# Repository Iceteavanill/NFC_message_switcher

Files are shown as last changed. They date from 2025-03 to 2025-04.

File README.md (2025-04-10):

[comment]: <> "LTeX: language=en-GB"

# NFC message switcher

This project is an implementation of an NFC tag which is able to change the message. It communicates to a host device. It was developed to be quickly assembled and easy to use but still be a bit more than a blinking light. It uses the reference implementation for the [bare metal TWI driver](https://github.com/microchip-pic-avr-examples/attiny1627-bare-metal-twi-mplab).
PCB render

## Main principle of operation

The main device is the [ST25DV04K](https://www.st.com/resource/en/datasheet/st25dv04k.pdf). 
It can communicate via NFC and I2C. 
When an NFC capable device is held near the PCB, the ST25DV04K starts to receive power and starts communicating with the device. 
The Power that's transmitted is shared (energy harvesting mode) with a [ATtiny402](http://ww1.microchip.com/downloads/en/DeviceDoc/ATtiny202-402-AVR-MCU-with-Core-Independent-Peripherals_and-picoPower-40001969A.pdf). 
When powered it starts communicating via I2C and writes to the user accessible memory. 
When the written data has been confirmed, it powers down.

## Details

### Power

Power provider is the energy harvesting mode of the ST25DV04K, the power source is a NFC capable device that is in proximity of the PCB.
It is buffered via a 47μF capacitor.
Because of that, it is essential to keep the power consumption of the ATtiny as low as possible.
Consult the source code for more details.

### Link arbitration

The ST25DV04K does only support I2C *or* NFC active at the same time. 
However, it has an open drain output that can be used to sense the current activity. 
Low, signals that the device is currently busy. 
The ATtiny then waits for the device to be available, by waiting in sleep. 
A hardware interrupt is not yet implemented.

### Device configuration

The ST25DV04K needs some configuration for correct operation. 
The energy harvesting mode must be enabled/forced at startup. 
Also, the GPO mode must be set to RF_ACTIVITY_EN to enable better link arbitration.
The configuration happens after the ATtiny has been programmed once.

### Antenna

The antenna / coil design is based on a [paper](https://www.researchgate.net/publication/339137261_Inductance_Formula_for_Rectangular_Planar_Spiral_Inductors_with_Rectangular_Conductor_Cross_Section) from Hubert Aebischer. 
The ST25DV04K has an internal tuning capacitor which should be assumed to be 29pF.
Based on that, the inductance should be 4.75μH. 

### Formfactor

The PCB dimensions are the same as a credit card.
It is however quite a bit thicker.

# Building your own

All required files to recreate this project can be found [here](https://github.com/Iceteavanill/NFC_message_switcher/releases/tag/1.0.0). 

## Sourcing

The following parts are needed to recreate this Project (as well as the PCB):

| Reference 	| Value 	| Qty 	| Digikey number 	|
|:---:	|:---:	|:---:	|:---:	|
| C1, C3 	| 0.1uF 	|  2  	| 1276-1000-1-ND 	|
| C2 	| 47uF 	|  1  	| 1276-3063-2-ND 	|
| R1, R2 	| 4k7 	|  2  	| MMA-4.7KACT-ND 	|
| U1 	| ATtiny402 	|  1  	| ATTINY402-SSNRCT-ND 	|
| U2 	| ST25DV04K 	|  1  	| 497-17123-1-ND 	|

## Assembly

There are no special requirements for the assembly of the PCB's. 
If you are used to soldering SMD components it shouldn0t be a problem. 

## Software

You can use the provided released hex file, however it is recommended to customize the software to your own taste. 

There are multiple options to customize the software

> [!WARNING]  
> I tried making the process of using the software as easy as possible, however it may not be very easy/beginner-friendly in places.

### Overview

Customizing the software always requires a rebuild of the firmware of the Attiny. 
The XC8 compiler from microchip is recommended. 
The following flags were used and are recommended:

| Flags | commands |
|---|---|
| Global | -gdwarf-3 -mconst-data-in-progmem -mno-const-data-in-config-mapped-progmem |
| compiler | -funsigned-char -funsigned-bitfields -Wall -O2 -fno-common |
| linker | "libm" -Wl,--gc-sections |

A makefile is already prepared with all the required flags. 
If you install a later version you might have to alter the paths a little.

For customization, only a header file has to be altered (```nfc_messages.h```).  
There are multiple ways of accomplishing that:

 * editing the header directly (not recommended)
 * using the python script
 * using the gui (recommended)

### Editing the header directly

Editing the header directly is not recommended because the required data must be in the NDEF format. 
Manually generating that is very tedious. 
If you have special needs however, like encoding special data types, you have to do it this way because anything else has not been implemented.

### Using the pyton script

The ```dataGenerator.py``` python script can be used to quickly generate custom messages. 
It requires the NDEFLib python library. 
Edit the ```message_as_text_list``` list with your messages and then run the script:
```py
message_as_text_list = ["Test 1",
                        "Test 2 a bit longer",
                        "Test 3 even looooooooooooooooooooooooooonger",
                        "https://www.youtube.com/watch?v=dQw4w9WgXcQ",
                        "spotify:track:4cOdK2wGLETKBW3PvgPWqT"
]
```
### Using the gui

A gui has been made to quickly program multiple NFC tags. 
It requires WXpython and uses the previously mentioned script and the ```message_as_text_list```.
For uploading, it relies on the MPLAB IPE programming software and its command line interface.

Programming steps:

1. Step:

Enter your desired message(s) in the table at the top. 
Links to websites videos or Spotify songs are also allowed.

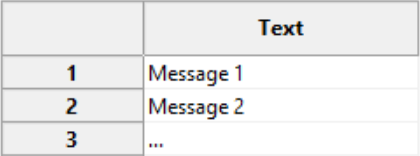
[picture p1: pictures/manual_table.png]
picture of the table


2. Step:

If your main device is an iPhone check the ```iPhone compatability mode```. 
IPhones are unable to read text from a NFC device, and the text messages have to be encoded as a website.

3. Step:

Some default messages are added to the list automatically. If you don't want that, you can disable that with the checkbox ```Remove predefined texts```. 
The ```message_as_text_list``` from ```dataGenerator.py``` is used as a source.

4. Step:

Connect your programmer to the tag and press program device. 
The build and upload steps are automatically executed.

### Building and uploading

In all options but the gui you have to manually build and then upload the firmware. 
You can use the ``` make upload ``` command with the option ``` PROGTOOL= ``` to select the programmer that you have on hand. 
See the documentation of the IPE programmer option to know which flag you have to use.

## Batch programming

Many devices in a row can be programmed with the programming jig:

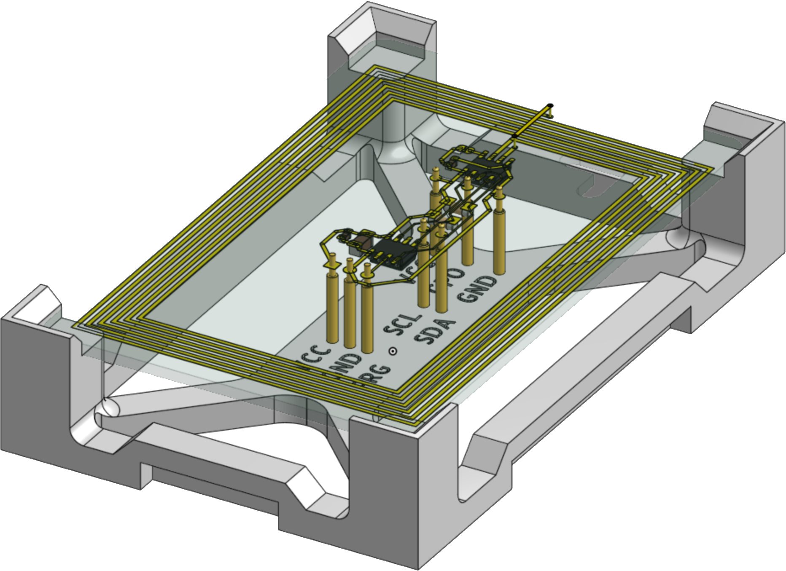
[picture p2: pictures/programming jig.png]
programming jig


It was designed in Onshape. 
I used pogopins that I had on hand. 
You probably want to customize it to your current stock. 
You find the Onshape document [here](https://cad.onshape.com/documents/450623688917edcaa975b9e7/w/39588c936aa9381f65fac7c0/e/be57d568f84f27791dc539d2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).

## Rating GUI

Because this PCB was designed as a competition PCB, a rating gui has been made using streamlit. 
You can import a CSV of contestants and rate each one for time, quality and some other points. 
It is meant to be customized to your particular use case. 

# Caveat

It must be noted that the current design has a (obvious) flaw. 
The ATtiny is in the middle of the coil and *probably* quite affected by the activity of it. 
When combined with the nonideal power delivery method, this can significantly impair functionality at times (The I2C content that is written gets verified but I2C has no error correcting method).
Some more analysis in that regard is not yet made.

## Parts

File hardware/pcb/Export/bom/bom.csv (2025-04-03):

Reference | Value | Datasheet | Footprint | Qty | DNP | Digikeynumber
C1 | 0.1uF | ~ | Capacitor_SMD:C_0603_1608Metric_Pad1.08x0.95mm_HandSolder | 1 |  | 1276-1000-1-ND
C2 | 47uF | ~ | Capacitor_SMD:C_1206_3216Metric_Pad1.33x1.80mm_HandSolder | 1 |  | 1276-3063-2-ND
C3 | 0.1uF | ~ | Capacitor_SMD:C_0603_1608Metric_Pad1.08x0.95mm_HandSolder | 1 | DNP | 1276-1000-1-ND
R1,R2 | 4k7 | ~ | Resistor_SMD:R_MiniMELF_MMA-0204 | 2 |  | MMA-4.7KACT-ND
U1 | ATtiny402 | http://ww1.microchip.com/downloads/en/DeviceDoc/ATtiny202-402-AVR-MCU-with-Core-Independent-Peripherals_and-picoPower-40001969A.pdf | Package_SO:SOIC-8_3.9x4.9mm_P1.27mm | 1 |  | ATTINY402-SSNRCT-ND
U2 | ST25DV04K | https://www.st.com/resource/en/datasheet/st25dv04k.pdf | Package_SO:SOIC-8-1EP_3.9x4.9mm_P1.27mm_EP2.29x3mm | 1 |  | 497-17123-1-ND

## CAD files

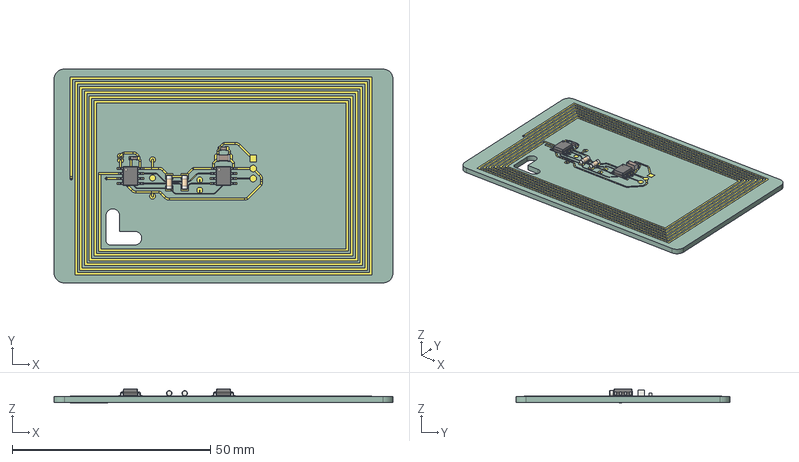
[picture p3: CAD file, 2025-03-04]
hardware/pcb/Export/step/nfc tag.step
85.6 x 54.0 x 3.44 mm
SOIC_8_39x49mm_P127mm x 2
C_0603_1608Metric x 2
R_MiniMELF_MMA-0204 x 2
C_1206_3216Metric
nfc_tag_track_1
nfc_tag_track_2
nfc_tag_track_3
nfc_tag_track_4
nfc_tag_track_5
nfc_tag_track_6
nfc_tag_track_7
nfc_tag_track_8
nfc_tag_track_9
nfc_tag_track_10
nfc_tag_track_11
nfc_tag_track_12
nfc_tag_track_13
nfc_tag_track_14
nfc_tag_track_15
nfc_tag_track_16
nfc_tag_track_17
nfc_tag_track_18
nfc_tag_track_19
nfc_tag_track_20
nfc_tag_track_21
nfc_tag_track_22
nfc_tag_track_23
nfc_tag_track_24
nfc_tag_track_25
nfc_tag_track_26
nfc_tag_track_27
nfc_tag_track_28
nfc_tag_track_29
nfc_tag_track_30
nfc_tag_track_31
nfc_tag_track_32
nfc_tag_track_33
nfc_tag_track_34
nfc_tag_track_35
nfc_tag_track_36
nfc_tag_track_37
nfc_tag_track_38
nfc_tag_track_39
nfc_tag_track_40
nfc_tag_track_41
nfc_tag_track_42
nfc_tag_track_43
nfc_tag_track_44
nfc_tag_track_45
nfc_tag_track_46
nfc_tag_track_47
nfc_tag_track_48
nfc_tag_track_49
nfc_tag_track_50
nfc_tag_track_51
nfc_tag_track_52
nfc_tag_track_53
nfc_tag_track_54
nfc_tag_track_55
nfc_tag_track_56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

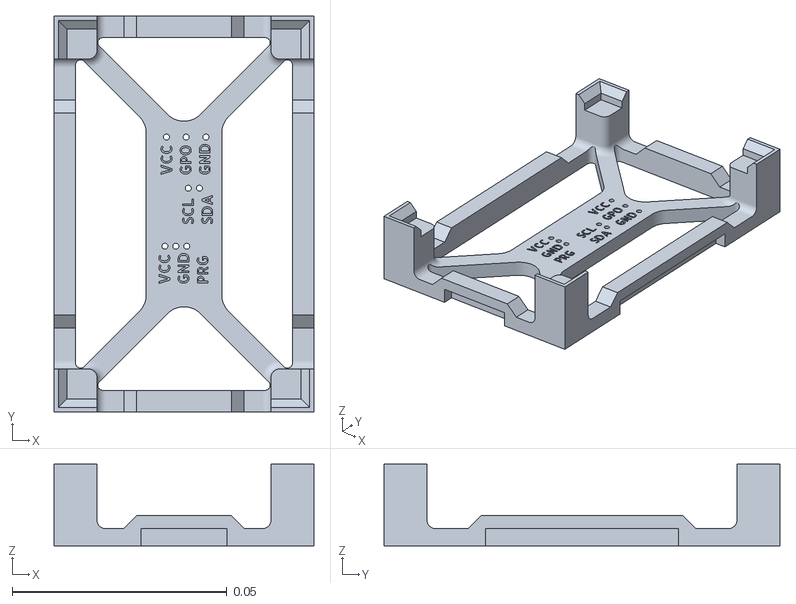
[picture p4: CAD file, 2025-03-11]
hardware/programming jig/programming jig.stl
0.0605 x 0.0921 x 0.019

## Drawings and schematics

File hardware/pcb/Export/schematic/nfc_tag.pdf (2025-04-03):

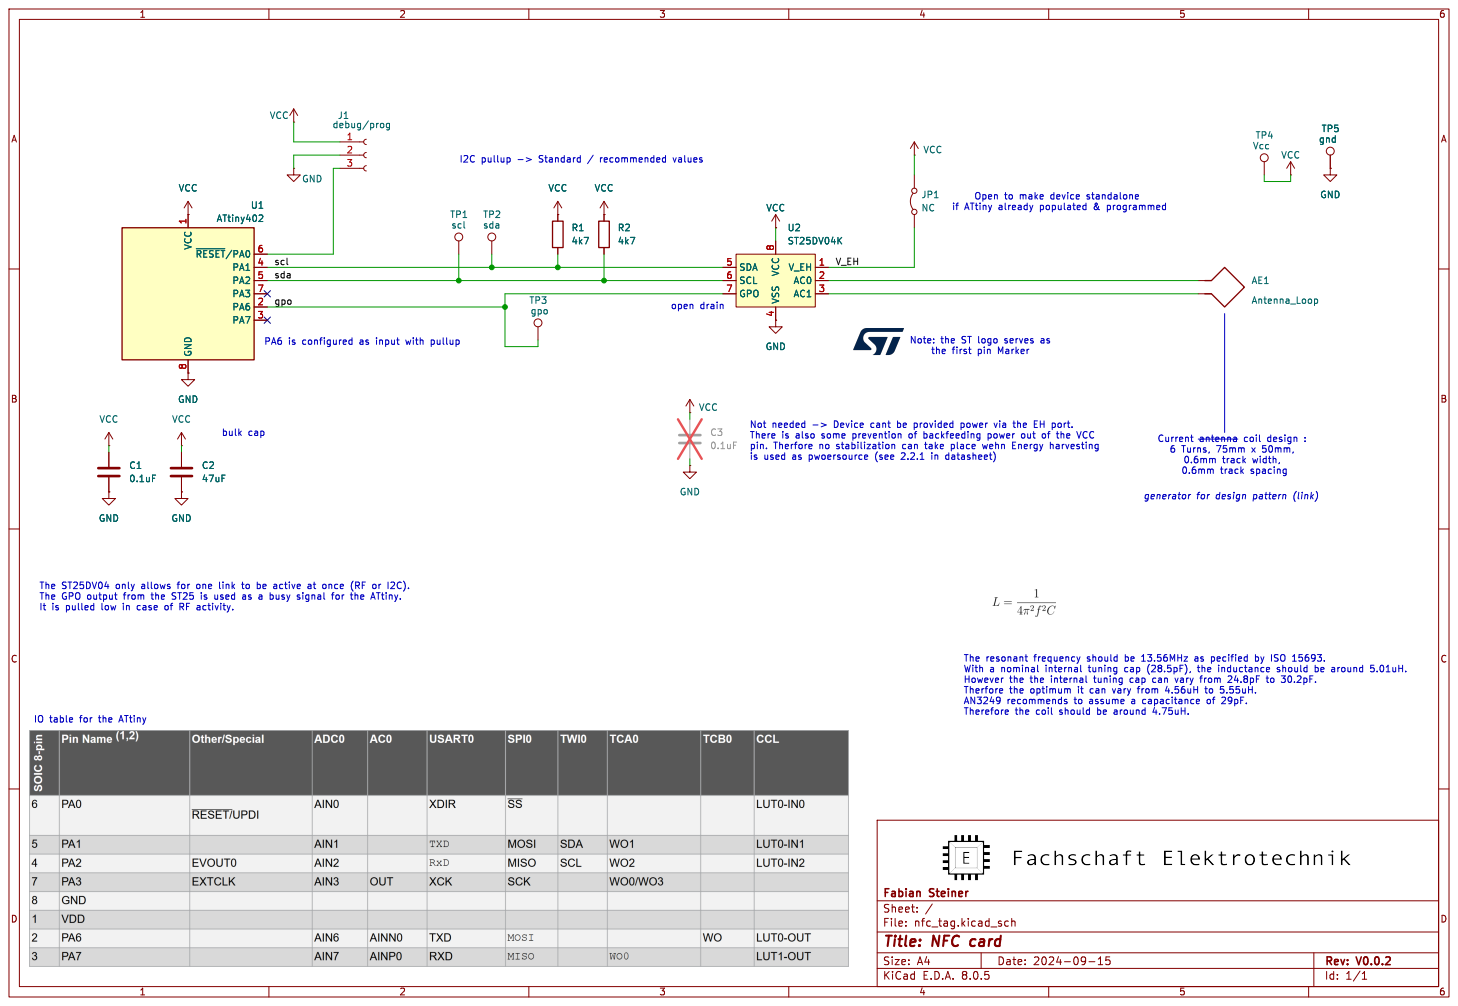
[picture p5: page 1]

Open to make device standalone

4 SDA 5 SCL 6 GPO 7 VCC

File: nfc_tag.kicad_sch Sheet: / Fabian Steiner

Id: 1/1 Title: NFC card

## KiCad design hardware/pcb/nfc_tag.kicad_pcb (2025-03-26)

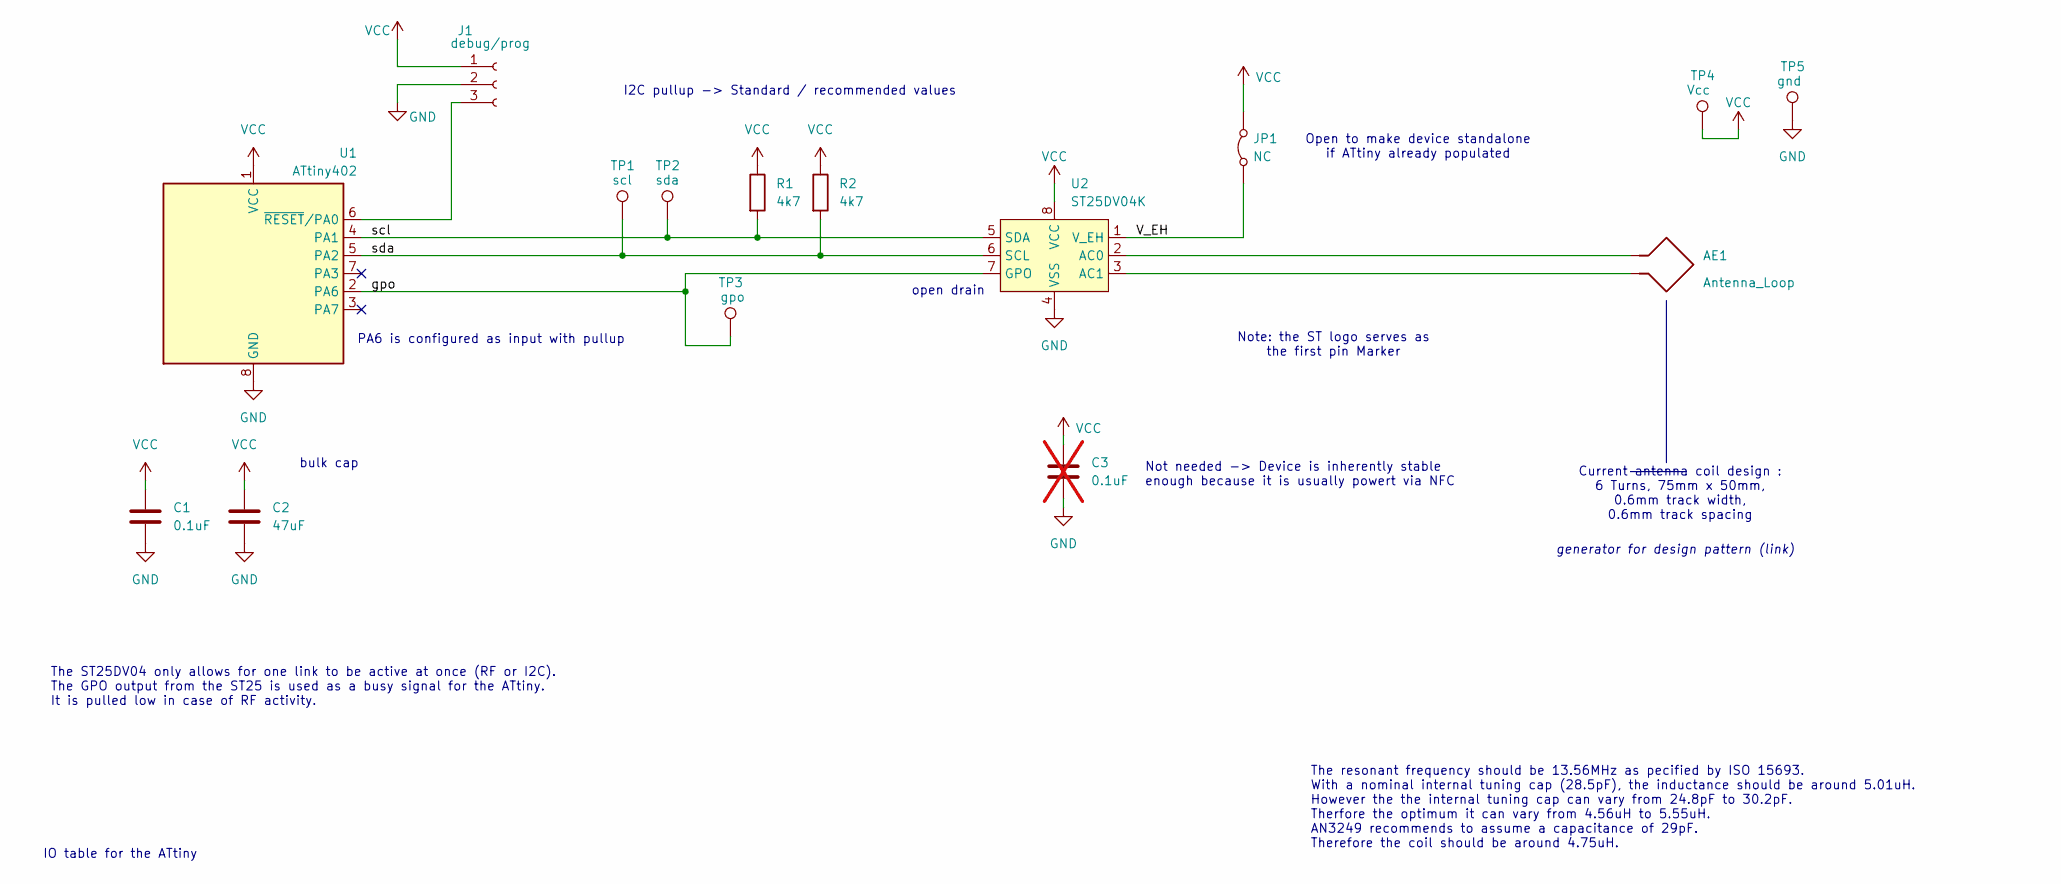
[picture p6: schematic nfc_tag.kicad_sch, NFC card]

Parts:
AE1: Antenna_Loop; nfc antenna_optimized
C1: 0.1uF; C_0603_1608Metric_Pad1.08x0.95mm_HandSolder; Digikeynumber 1276-1000-1-ND
C2: 47uF; C_1206_3216Metric_Pad1.33x1.80mm_HandSolder; Digikeynumber 1276-3063-2-ND
C3: 0.1uF; C_0603_1608Metric_Pad1.08x0.95mm_HandSolder; Digikeynumber 1276-1000-1-ND; not fitted
J1: debug/prog; debug_pads
JP1: NC; SolderJumper-2_P1.3mm_Bridged2Bar_RoundedPad1.0x1.5mm
R1, R2: 4k7; R_MiniMELF_MMA-0204; Digikeynumber MMA-4.7KACT-ND
TP1: scl; TestPoint_Pad_D1.5mm
TP2: sda; TestPoint_Pad_D1.5mm
TP3: gpo; TestPoint_Pad_D1.5mm
TP4: Vcc; TestPoint_Pad_D1.5mm
TP5: gnd; TestPoint_Pad_D1.5mm
U1: ATtiny402; SOIC-8_3.9x4.9mm_P1.27mm; Digikeynumber ATTINY402-SSNRCT-ND
U2: ST25DV04K; SOIC-8-1EP_3.9x4.9mm_P1.27mm_EP2.29x3mm; Digikeynumber 497-17123-1-ND

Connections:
/V_EH: JP1.1 (A), U2.1 (V_EH)
/gpo: TP3.1, U1.2 (PA6), U2.7 (GPO)
/scl: R1.2, TP2.1, U1.4 (PA1), U2.5 (SDA)
/sda: R2.2, TP1.1, U1.5 (PA2), U2.6 (SCL)
GND: C1.2, C2.2, C3.2, J1.2, TP5.1, U1.8 (GND), U2.4 (VSS)
unnamed: J1.3, U1.6 (~RESET/PA0)
unnamed: AE1.1, U2.2 (AC0)
unnamed: AE1.2, U2.3 (AC1)
VCC: C1.1, C2.1, C3.1, J1.1, JP1.2 (B), R1.1, R2.1, TP4.1, U1.1 (VCC), U2.8 (VCC)

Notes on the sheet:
The resonant frequency should be 13.56MHz as pecified by ISO 15693. With a nominal internal tuning cap (28.5pF), the inductance should be around 5.01uH. However the the internal tuning cap can vary from 24.8pF to 30.2pF. Therfore the optimum it can vary from 4.56uH to 5.55uH. AN3249 recommends to a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
Not needed -> Device is inherently stable enough because it is usually powert via NFC
IO table for the ATtiny
I2C pullup -> Standard / recommended values
The ST25DV04 only allows for one link to be active at once (RF or I2C). The GPO output from the ST25 is used as a busy signal for the ATtiny. It is pulled low in case of RF activity.
PA6 is configured as input with pullup
bulk cap
Current antenna coil design : 6 Turns, 75mm x 50mm, 0.6mm track width, 0.6mm track spacing
generator for design pattern (link)
open drain
Note: the ST logo serves as the first pin Marker
Open to make device standalone if ATtiny already populated

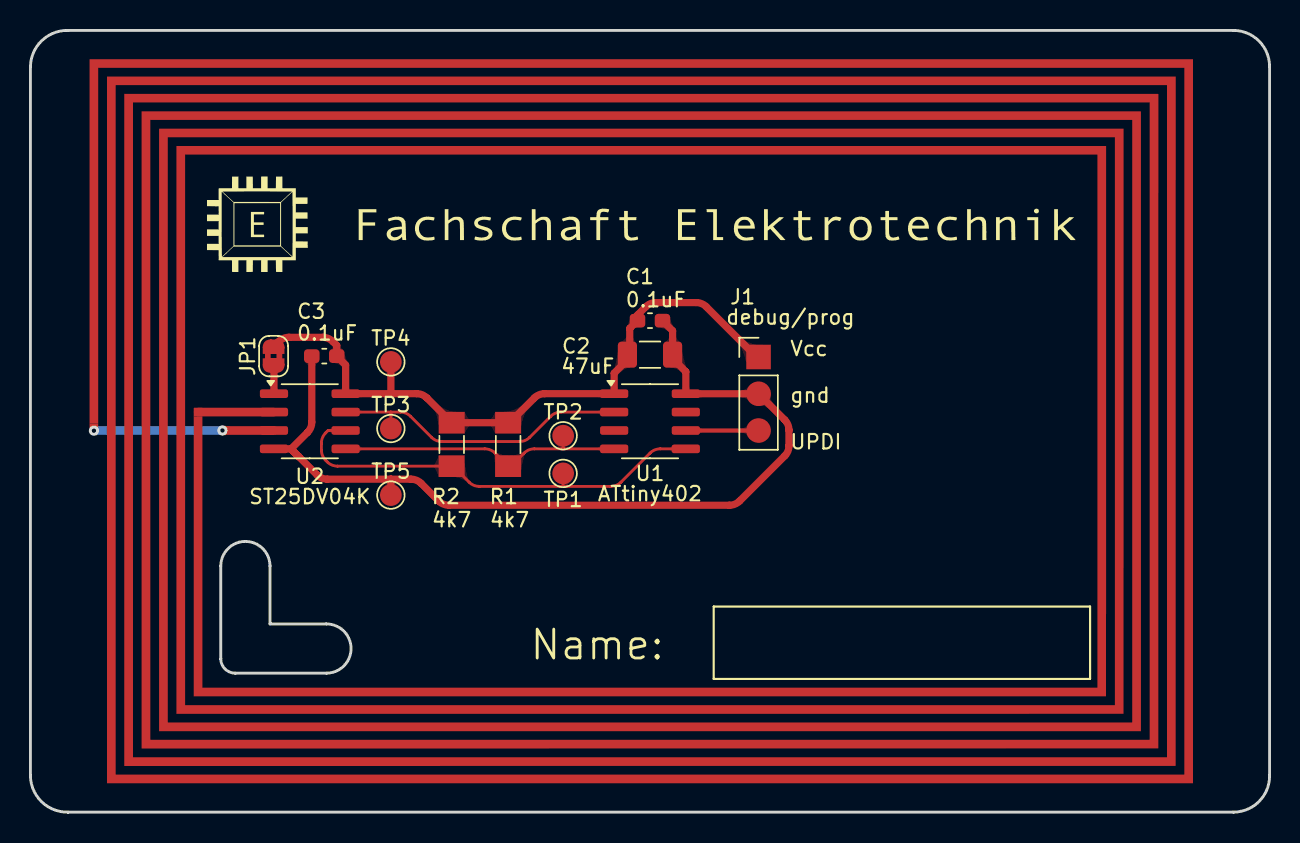
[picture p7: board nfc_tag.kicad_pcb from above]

Board: 2 copper layers, 85.6 x 54.0 mm, 15 parts (0 on the bottom side), 9 nets.

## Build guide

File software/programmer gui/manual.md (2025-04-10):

[comment]: <> (pandoc -f gfm -t html manual.md -o manual.htm -s --metadata title="Manual")
[comment]: <> "LTeX: language=en-GB" 

# Step 1
Enter your desired message(s) in the table at the top. 
Links to websites or videos must start with "http".
Spotify songs are also allowed and must start with "spotify:".

picture of the table

# Step 2
If your main device is an iPhone check the ```iPhone compatability mode```. 
IPhones are unable to read text from a NFC device, and the text messages have to be encoded as a website.

# Step 3
Some default messages are added to the list automatically. 
If you don't want that, you can disable that with the checkbox.
<span style="color:red">If you are a lecturer, you MUST tick this box</span>.

# Step 4
Press the NFC Tag firmly into the jig. 
If the programmer light is on (red or green depending on the programmer), the NFC tag is correctly inserted.
When correctly inserted, you can start programming the device by pressing program device. 
Keep the NFC tag pressed in the jig until the wait message disappears!
If a Programmer error appears, inform a supervisor.

# Step 5
Check if your tag works.

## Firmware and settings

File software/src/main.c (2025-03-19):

/*
This software was written by Fabian Steiner for the NFC_message_switcher Project.
It is provided AS IS with no liability for anything this software may or may not be the cause of.
For more information check the github readme.
This Project uses various AVR libraries aswell as the PIC bare metal reference driver
*/

#include <xc.h>
#include <stdint.h>
#include <stdbool.h>
#include <avr/io.h>
#include <avr/eeprom.h>
#include <avr/sleep.h>
#include <avr/interrupt.h>
#include "TWI_host.h"
#include "nfc_messages.h"

// EEprom Data adresses
uint8_t *EEpromIncAdr = (uint8_t *)0x00;  // Adress for incremental acces counting (gets looped around after 255)
uint8_t *EEpromInitAdr = (uint8_t *)0x01; // Adress for storage of Initialisation status

// pointer to data that should be writen to the defined registers
uint8_t EHMData = 0x00;
uint8_t GPOData = 0x82;

// functions

// func to go to sleep indefinitely -> after NFC tag has been written
void nightynighty();
// function to go to sleep but also read Interrupt and wake up
void nightyWakey();
// init the timer for periodic interrupt
void init_timer();
// harware wait(with timer and interupt)
void harwareWait();

// fuse definition
FUSES = {
    .WDTCFG = 0x00,  // WDTCFG {PERIOD=OFF, WINDOW=OFF}
    .BODCFG = 0x05,  // BODCFG {SLEEP=ENABLED, ACTIVE=ENABLED, SAMPFREQ=1KHz, LVL=BODLEVEL0}
    .OSCCFG = 0x01,  // OSCCFG {FREQSEL=16MHZ, OSCLOCK=CLEAR}
    .TCD0CFG = 0x00, // TCD0CFG {CMPA=CLEAR, CMPB=CLEAR, CMPC=CLEAR, CMPD=CLEAR, CMPAEN=CLEAR, CMPBEN=CLEAR, CMPCEN=CLEAR, CMPDEN=CLEAR}
    .SYSCFG0 = 0xF6, // SYSCFG0 {EESAVE=CLEAR, RSTPINCFG=UPDI, CRCSRC=NOCRC}
    .SYSCFG1 = 0x07, // SYSCFG1 {SUT=64MS} -> must be 64ms or the Capacitor does not have enough time to charge enough
    .APPEND = 0x00,  // APPEND {APPEND=User range:  0x0 - 0xFF}
    .BOOTEND = 0x00, // BOOTEND {BOOTEND=User range:  0x0 - 0xFF}
};

LOCKBITS = 0xC5; // {LB=NOLOCK}

int main()
{
    // set clock configuration
    CLKCTRL.MCLKCTRLA &= ~CLKCTRL_CLKSEL_gm;          // clear configuration (set to 0)
    CLKCTRL.MCLKCTRLA |= CLKCTRL_CLKSEL_OSCULP32K_gc; // set clock to internal 32kHz LP clock
    CLKCTRL.MCLKCTRLB &= ~CLKCTRL_PEN_bm;             // Disable internal Clock Divider (for now))
    CLKCTRL.MCLKLOCK |= 1;                            // lock clock configuration

    // Init I2C connection
    TWI_initHost();

    // Set PA6 (GPO input) as input
    PORTA.DIRCLR |= PIN6_bm;
    // enable pullup (is needed because open drain output)
    PORTA.PIN6CTRL |= PORT_PULLUPEN_bm;

    // check if the ST25DV04 device has been Inited
    if (eeprom_read_byte(EEpromInitAdr) != 0x69)
    {
        // Password for system access (default)
        uint8_t defaultpasswordSequence[] = {0x00, 0x00, 0x00, 0x00, 0x00, 0x00, 0x00, 0x00, 0x09, 0x00, 0x00, 0x00, 0x00, 0x00, 0x00, 0x00, 0x00};

        bool slaveDeviceError = false;

        // Provide Password to ST25DV device
        if (!TWI_sendBytesToRegister(SLAVE_ADDRESS_SYSTEM, SysReg_PasswordAdr, &defaultpasswordSequence[0], 17))
        {
            slaveDeviceError = true;
        }
        harwareWait();

        // now that a Secure session is open -> write EH mode
        if (!TWI_sendBytesToRegister(SLAVE_ADDRESS_SYSTEM, SysReg_EH_MODE, &EHMData, 1))
        {
            slaveDeviceError = true;
        }
        harwareWait();

        // write GPO mode
        if (!TWI_sendBytesToRegister(SLAVE_ADDRESS_SYSTEM, SysReg_GPO, &GPOData, 1))
        {
            slaveDeviceError = true;
        }
        harwareWait();

        // check if writing to device was successfull
        if (slaveDeviceError)
        {
            // cant do anything stop wait here for debug
            nightynighty();
            return -1;
        }
        harwareWait();

        // check EH mode
        if (!TWI_VerifyBytes(SLAVE_ADDRESS_SYSTEM, SysReg_EH_MODE, &EHMData, 1))
        {
            slaveDeviceError = true;
        }
        harwareWait();

        // check GPO mode
        if (!TWI_VerifyBytes(SLAVE_ADDRESS_SYSTEM, SysReg_GPO, &GPOData, 1))
        {
            slaveDeviceError = true;
        }

        // if all good (writing to device was successfull)
        if (!slaveDeviceError)
        {
            // ST25dv was initialized -> mark as initialized
            eeprom_write_byte(EEpromInitAdr, 0x69);
        }
        else
        {
            // cant do anything stop wait here for debug
            nightynighty();
            return -1;
        }
    }

    // datapointer
    const uint8_t *pData;

    // read eeprom inc adress
    uint8_t eepromData = eeprom_read_byte(EEpromIncAdr);

    // clamp eeprom adress
    if (eepromData == 255)
    {
        eepromData = 0;
    }
    else
    {
        eepromData++;
    }

    // get message from array
    pData = nfcMessages[eepromData % messageNumber];

    // current state of message transfer (0, 1, 3)
    uint8_t state = 0;
    // Counter for tries, only allow 5 tries (arbitrary)
    uint8_t tries = 0;
    // write message to NRF device
    while (state != 3 && tries <= 5)
    {

        if ((PORTA.IN & PIN6_bm))
        {

            // pin is high go to next step
            if (state == 0)
            {
                // pData[5] contains the message lenght for the Ndef Payload. +7 to add header length
                if (TWI_sendBytesToRegister(SLAVE_ADDRESS_USER, 0, pData, pData[5] + 7))
                {
                    state = 1;
                }
            }
            else
            {
                if (TWI_VerifyBytes(SLAVE_ADDRESS_USER, 0, pData, pData[5] + 7))
                {
                    // readback was positive, end loop
                    state = 3;
                    break;
                }
                else
                {
                    // readback was negative (Write transfer or readtransfer failed)
                    tries++;
                    state = 0;
                }
            }
        }
        harwareWait();
    }

    // store incremented Eeprom adress
    eeprom_write_byte(EEpromIncAdr, eepromData);

    // go to sleep
    nightynighty();

    // never reached (hopefully)
    return 0;
}

void nightynighty()
{
    set_sleep_mode(SLEEP_MODE_PWR_DOWN);
    sleep_enable();
    sleep_cpu(); // Enter sleep mode
}

void nightyWakey()
{
    set_sleep_mode(SLEEP_MODE_STANDBY); // sleep mode standby to recover by timers
    sleep_enable();
    sei();           // Enable interrupts
    sleep_cpu();     // Enter sleep mode
    sleep_disable(); // Disable sleep mode after waking up
    // cli();                 // Disable interrupts
    TCB0.CTRLA &= ~TCB_ENABLE_bm; // Disable the timer
    TCB0.CNT = 0;                 // Reset the timer value in case of future use
}

// ISR for timer B
ISR(TCB0_INT_vect)
{
    TCB0.INTFLAGS = TCB_CAPT_bm; // Clear interrupt flag
    sleep_disable();             // Disable sleep mode after waking up
}

// Set the timer to generate an interrupt every 1000ms
void init_timer()
{
    TCB0.CTRLA |= TCB_CLKSEL_CLKDIV2_gc;             // Clock source: CLK_PER / 2 (16.384 kHz)
    TCB0.CTRLB |= TCB_CNTMODE_INT_gc;                // Periodic interrupt mode
    TCB0.CCMP = 65530;                               // Set period for 100ms (16,384 Hz clock)
    TCB0.INTCTRL |= TCB_CAPT_bm;                     // Enable interrupt on capture/compare match
    TCB0.CTRLA |= (TCB_ENABLE_bm | TCB_RUNSTDBY_bm); // Enable TCB and allow run in standby
}

// harware wait function
void harwareWait()
{
    init_timer();
    nightyWakey();
}

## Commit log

2025-03-04 initial hardware commit
    [bom.csv, nfc tag.step, nfc_tag.kicad_pcb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]
2025-03-05 minor changes and corrections
    [main.c]
2025-03-08 Changed library to reference bare metal TWI drivers rewrote software accordingly edited jupyter notebook
2025-03-11 added programming jig
    [programming jig.stl]
2025-03-26 Made finaly hardware Export Edited color of PCB in file
    [nfc_tag.kicad_pcb]
2025-03-30 Added rating_gui. A streamlit application to speed up the rating of many PCB's. Added gitignore to accomodate a subfolder that gets written for a backup
2025-03-30 bugfixes mainly adding keys to critical buttons clearing search bar because it was making things difficult
2025-04-03 improved schematic clarity and fixed sight mistake in csv
    [bom.csv, nfc_tag.kicad_sch]
2025-04-13 Added delete Backupfile button Added another rating option
